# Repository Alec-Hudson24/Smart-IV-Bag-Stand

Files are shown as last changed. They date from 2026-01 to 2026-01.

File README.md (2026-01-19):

# Smart-IV-Bag-Stand
**Automated, height-adjustable IV pole with real-time fluid level monitoring and low-fluid alerts**  
*(Group project: Mechanical design, electronics integration, Arduino programming)*

## Goal/ Overview
- **Primary Features**:
  - Motorized height adjustment: Automatically or manually raise/lower the IV bag between 5 ft and 7 ft for ergonomic patient/nurse access.
  - Continuous fluid level tracking: Uses a load cell/weight sensor to monitor IV bag volume.
  - Low-fluid alert: Buzzer sounds and visual indicator activates when fluid drops below 20%.
- **Motivation**: Improve hospital efficiency and patient safety by reducing manual adjustments and preventing dry IV bags.
- **Outcome**: Fully functional prototype with joystick/rotary dial controls, LED feedback (green/yellow/red for full → low), calibration button, and hinged access panel for electronics.

## Programs and skills required
- **3D Modeling & Design**: SolidWorks (parametric modeling, assemblies, STEP export for prototyping/fabrication)
- **Electronics**: Soldering, PCB connections, integration of load cell, motors, joystick, rotary encoder, LEDs, buzzer
- **Programming**: Arduino IDE (sensor reading, motor control, state machine for modes/alerts, calibration logic)
- **Other**: Team collaboration, project planning, fabrication/assembly

## Key Takeaways and lessons
- Align tasks with team members' interests → higher quality work and motivation.
- Clear, ongoing communication (plans, roles, timelines) keeps everyone aligned and reduces rework.
- Build team rapport outside project work → improves collaboration and problem-solving.

 # Project Links  
-Video explanation and test: [IV Bag Stand Demo](https://www.youtube.com/watch?v=gjZ4MjLh-VY)  
-Code Powering This Project: [Code](https://github.com/Alec-Hudson24/Smart-IV-Bag-Stand/blob/main/Final_With_Automatic_Raise_Lower.ino)  
-Step File to Prototype: [Solidworks prototype](IV%20Project.STEP)  
-Final Design Report: [Report](https://github.com/Alec-Hudson24/Smart-IV-Bag-Stand/blob/main/Final%20Design%20Report%20IV%20Bag%2011_26_25.pdf)

## Future Improvements / Ideas
- Add wireless alerts (e.g., Bluetooth to nurse station app)
- Integrate battery monitoring
- Refine mechanical stability for taller extensions
- Design custom PCB to simplify the wiring

# Model Photo
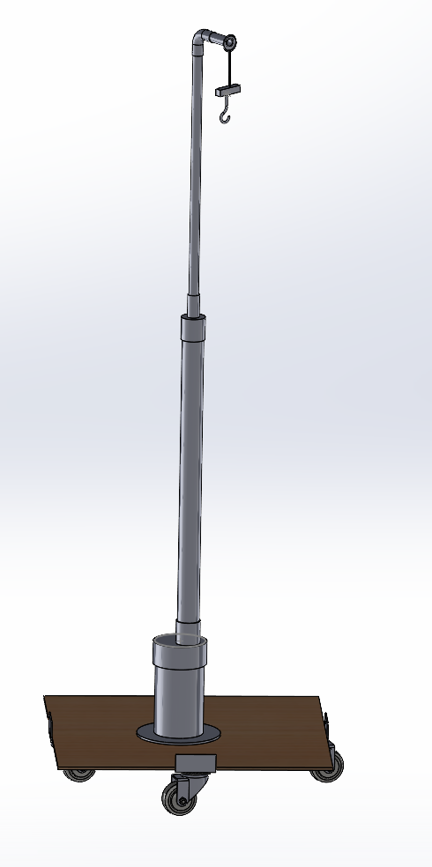
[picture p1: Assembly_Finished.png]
Finished IV Holder Assembly


*This was for a class called Concepts in Mechanical Design*

[Back](https://github.com/Alec-Hudson24)

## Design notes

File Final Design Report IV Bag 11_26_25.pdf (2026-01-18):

# Final Design Report Team 13

Alec Hudson, Jenna Sapong, Myles Knot, Caleb Crunk, Jackson Lynd

| Mech 3200 | assignment: Final Design Report IV Bag
Section 1 Team 13 | file: Final Design Report – Team 13 | 1 | Page

## Design Presentation

Executive Summary

This report details the IV bag height adjustment mechanism, an automated motorized IV pole with refill notification. It employs the following:
- Linear actuator for 5-7 ft height adjustment in <36 sec
- Load cell for fluid monitoring (alert at ~90 mL/0.09 kg)
- Arduino controls with joystick input
- Audible and Visual user feedback
- Stable and compact design
The design meets all DRS, costs $364.51, and outperforms manual poles in safety and efficiency. Trial readiness is proven through acceptance tests and performance metrics.
Machine Function
The device adjusts IV bag height (5-7 ft) via joystick and alerts via chime when fluid is low. It maximizes usability features across stakeholders of Users, Owners, Manufacturers and Support.

Design Requirement Specifications (DRS)
- Height: 5-7 ft in <36 sec.
- Load: 2.2-4.4 lbf (0.998 kg – 2kg).
- Alert at ~90 mL (0.09 kg).
- Budget: <$400.
- Alert Sound: >50 dB.
- Stability: No tipping/ease of transport.
Competitive Advantages
- Linear actuator chosen over rack/pinion or lever for off-the-shelf simplicity, constant velocity (1.34 in/s), and high load (89.9 lbf / 40.78 kg). Superior to manually lifting IV bags by reducing repetitive injuries, enabling single-user operation and auto-alert when bag is near empty.

Alec Hudson, Jenna Sapong, Myles Knot, Caleb Crunk, Jackson Lynd

| Mech 3200 | assignment: Final Design Report IV Bag
Section 1 Team 13 | file: Final Design Report – Team 13 | 2 | Page
- This design is optimized for stability and ease of transport as it retracts to the lowest compact size possible (under 5 feet) making moving through doorways and onto elevators is much simpler.
- Eliminates all manual efforts of lifting IV bags resulting in reduction of repetitive injury claims Proving Trial Readiness
Acceptance tests: Height adjustment 13.6 sec (pass); load to 4.4 lbf stable (pass); alert at 0.09 kg (pass); alert sound >50 dB (pass).
Performance Matrix
Requirement | Target | Performance | Status
Height | 5-7 ft | 5-7 ft (24” extension) | Pass
Time | <36 sec | 17.9 sec | Pass
Load | 2.2-4.4 lbf (0.998 kg – 2kg) | 89.9 lbf (40.78 kg) | Pass
Change in Mass Sensitivity | 0.005 kg | δ! = 0.005 kg (10 kg cell) | Pass
Budget | <$400 | $370.01 | Pass
Sound | >50 dB | ~90 dB | Pass

Cost Analysis
Bill of Materials
Component | OEM | Part Number | QTY | Cost/Unit | Total
Linear Actuator | JQDML | B0DH254XYJ | 1 | $104 | $104.00
MicroController | Arduino | Uno Rev3 | 1 | $27.60 | $27.60
LED Wheel | Adafruit | LED Ring Light | 1 | $16.95 | $16.95
Motor Shield | Arduino | Rev3 | 1 | $28.40 | $28.40
Thumb Joystick | Arduino | Grove | 1 | $6.00 | $6.00
Audio Buzzer | Passive Buzzer Naroote | | 1 | $0.50 | $0.50
Hanging Load Cell | DigiKey | 1568-21669-ND | 1 | $23.10 | $23.10
Plywood Base | Home Depot | 24”x24” | 1 | $12.87 | $12.87
PVC Tube Support | JM Eagle | 6”x10 ft D2729 | 1 | $26.31 | $26.31

Alec Hudson, Jenna Sapong, Myles Knot, Caleb Crunk, Jackson Lynd

| Mech 3200 | assignment: Final Design Report IV Bag
Section 1 Team 13 | file: Final Design Report – Team 13 | 3 | Page
PVC Flange Mount | Jones Stephens 7 in. O.D. | | 1 | $20.26 | $20.26
PVC Tube Extender | IPEX | 1/2 in. x10 ft SCH 40 | 2 | $4.96 | $9.92
PVC Connectors | Charlotte Pipe | 1/2 in. Coupling | 3 | $0.70 | $2.10
Caster Wheel Base | WEN | 24”x24” Dolly | 1 | $54.60 | $54.60
Handle | Manufactured | - | 1 | $20.00 | $20.00
Position Encoder | Arduino | KY-040 | 1 | $2.40 | $2.40
Misc. Hardware | Home Depot | Bolts/Nuts/Washers | 50 | $0.18 | $9.00
Total | | | | | $364.51
Final Design Overview
Key functionality for final IV Bag lift system that this design incorporates
- PVC/plywood base with casters for stability and low center of gravity
- Linear actuator for extension to required height, simple off-the-shelf components and compactness
- Load cell at top for weight/volume measurement providing required δ! mass sensitivity
- Arduino controller with joystick user input.
- LED visual level and calibration indicator and audible alert chime.
- Automates height and alerts low and empty fluid levels.

Alec Hudson, Jenna Sapong, Myles Knot, Caleb Crunk, Jackson Lynd

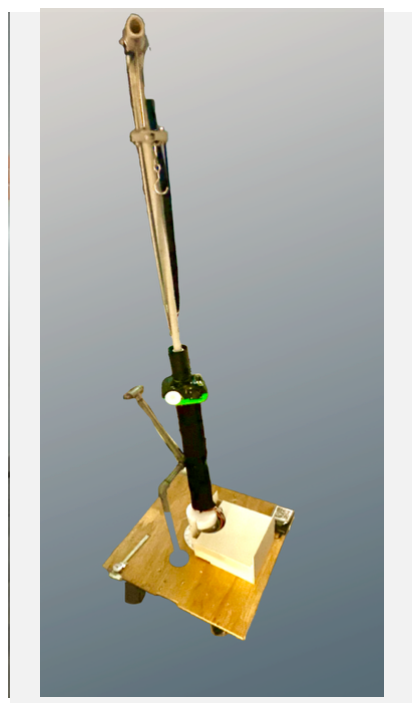
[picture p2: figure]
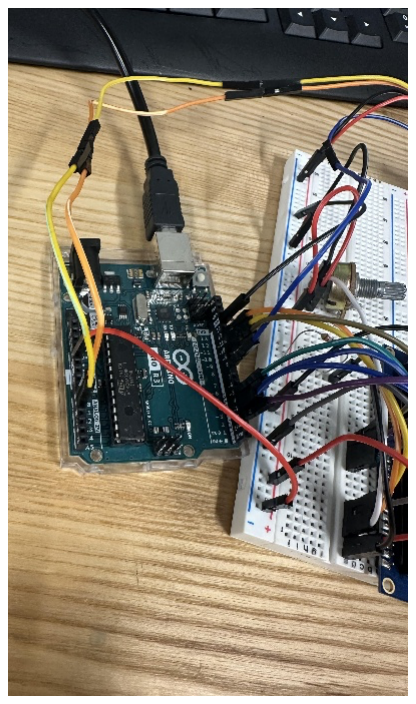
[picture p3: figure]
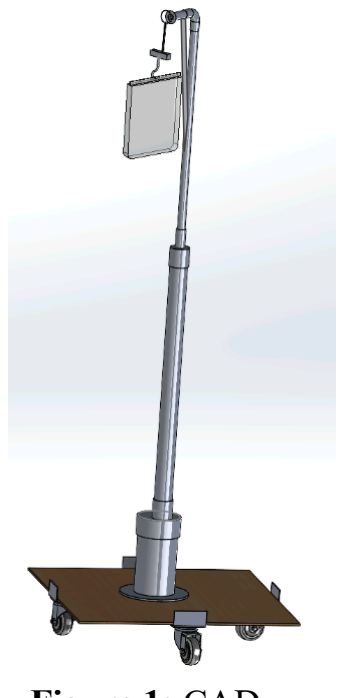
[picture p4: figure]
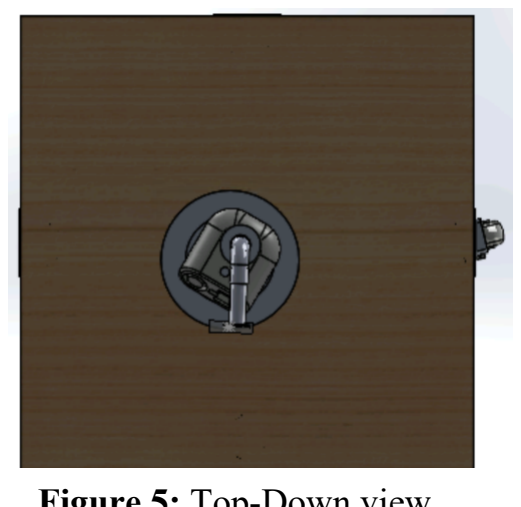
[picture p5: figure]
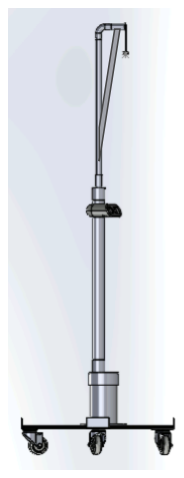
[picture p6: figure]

| Mech 3200 | assignment: Final Design Report IV Bag

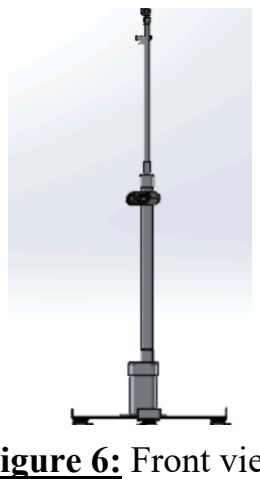
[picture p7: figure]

Section 1 Team 13 | file: Final Design Report – Team 13 | 4 | Page

CAD Model
SolidWorks model: Retracted (5 ft) and extended (7 ft) views, labeled base, actuator, load cell, joystick, LCD, chime.
- Figure 1: Depicts the CAD model that was used to build and wire the actual Device.
- Figure 2: Shows the wiring on the Arduino microcontroller that combines all the components into one device.
- Figure 3: Pictures the working IV stand prototype, completed, tested and operational. 3-View Line Drawings
Figure 1: CAD | Figure 2: Wiring | Figure 3: Machine as built
Figure 4: Side View | Figure 5: Top-Down view | Figure 6: Front view

Alec Hudson, Jenna Sapong, Myles Knot, Caleb Crunk, Jackson Lynd

| Mech 3200 | assignment: Final Design Report IV Bag
Section 1 Team 13 | file: Final Design Report – Team 13 | 5 | Page
- Figure 4: Depicts the side view providing a profile angle of the hook and loadcell showing 60-84” height range and caster mounting
- Figure 5: Shows the plan view which includes the profile of the IV stand and demonstrates the stable base with 24” square footprint
- Figure 6: shows the front view giving a good view of the user input control panel

Manufacturing Overview
Purchased Components | Fabricated Components
Arduino Controller/Wiring | 3D printed parts
Linear actuator | Assembly
Switches | Transportation Handle

Materials

Load Cell

Assembling components together and developing the code for this project was the main challenge, once the code was developed manufacturing was straight forward to meet DRS goals.

Key Manufacturing Process Steps
1. Bolt casters to 24” square base
2. Mount PVC Base in center of base
3. Install actuator and 3D printed cap
4. Install additional PVC assembly to house actuator
5. Install Load Cell and Lifting Arm
6. Wire Arduino per Figure 2 and upload operating software
7. Test Assembly for performance to design requirement specs Total assembly and test time ~2 hours

Alec Hudson, Jenna Sapong, Myles Knot, Caleb Crunk, Jackson Lynd

| Mech 3200 | assignment: Final Design Report IV Bag
Section 1 Team 13 | file: Final Design Report – Team 13 | 6 | Page

Conclusion

The IV bag design prioritizes accuracy and ease of assembly, aiding medical staff and manufacturers through intuitive user interfaces and precise load sensing. It meets all design requirements and delivers optimal performance for the environment it services. Ass seen in the Proving Trail Readiness section, this design meets or exceeds all design requirment specifications.

Design Methodology
Problem Statement and Customer Needs
Manual IV pole adjustments cause repetitive stress injuries, inefficiency, and lost revenue due to unchecked fluid levels.
The customer needs are as follows:
- Automated IV Bag elevation that is easily adjustable and single-user capable (End-User)
- Efficient that requires no manual labor (reduced claims) and alerts for IV bags nearing/reaching empty (Owners)
- Easy to assemble and low cost (Manufacturers)
- Modular design and stability allows for easy transportation, maintenance and troubleshooting (Support)

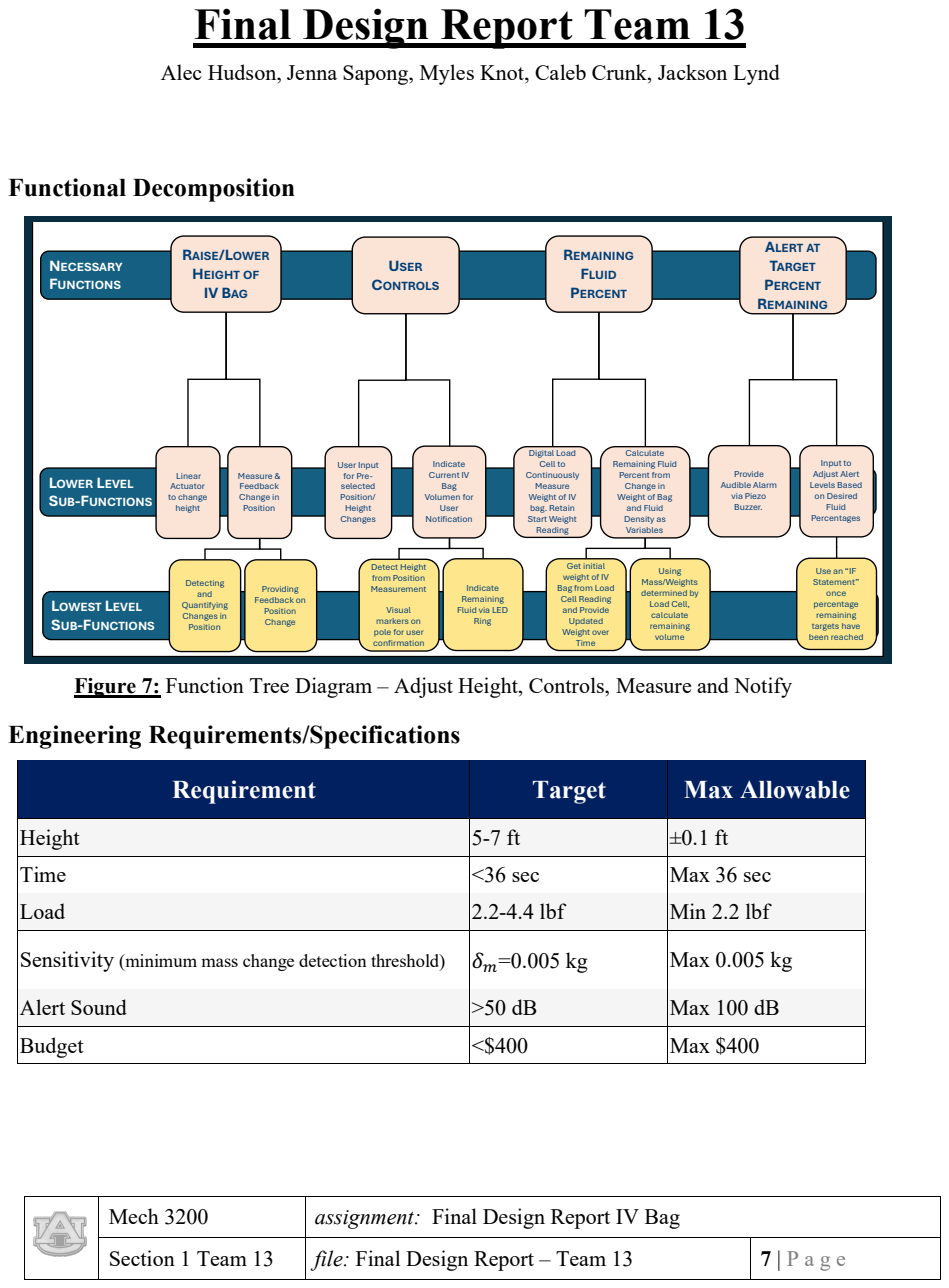
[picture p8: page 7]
Functional Decomposition; NECESSARY FUNCTIONS; LOWER LEVEL SUB-FUNCTIONS; USER CONTROLS; User Input for Pre- selected Position/ Height Changes; Indicate Current IV Bag Volumen for User Notification; REMAINING FLUID PERCENT; RAISE/LOWER HEIGHT OF IV BAG; Linear Actuator to change height; Measure & Feedback Change in Position; ALERT AT TARGET PERCENT REMAINING; Provide Audible Alarm via Piezo Buzzer.; Input to Adjust Alert Levels Based on Desired Fluid Percentages; LOWEST LEVEL SUB-FUNCTIONS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

Alec Hudson, Jenna Sapong, Myles Knot, Caleb Crunk, Jackson Lynd

Digital Load
Cell to
Continuously
Measure
Weight of IV
bag. Retain
Start Weight
Reading

Calculate
Remaining Fluid
Percent from
Change in
Weight of Bag
and Fluid
Density as
Variables

Get initial
weight of IV
Bag from Load
Cell Reading
and Provide
Updated
Weight over
Time

Use an “IF
Statement”
once
percentage
remaining
targets have
been reached

Indicate
Remaining
Fluid via LED
Ring

Visual
markers on
pole for user
confirmation

Figure 7: Function Tree Diagram – Adjust Height, Controls, Measure and Notify
Engineering Requirements/Specifications

Requirement | Target | Max Allowable

Height | 5-7 ft | ±0.1 ft
Time | <36 sec | Max 36 sec
Load | 2.2-4.4 lbf | Min 2.2 lbf

Sensitivity (minimum mass change detection threshold) | δ!=0.005 kg | Max 0.005 kg

Alert Sound | >50 dB | Max 100 dB
Budget | <$400 | Max $400

Mech 3200 | assignment: Final Design Report IV Bag
Section 1 Team 13 | file: Final Design Report – Team 13 | 7 | Page

Alec Hudson, Jenna Sapong, Myles Knot, Caleb Crunk, Jackson Lynd

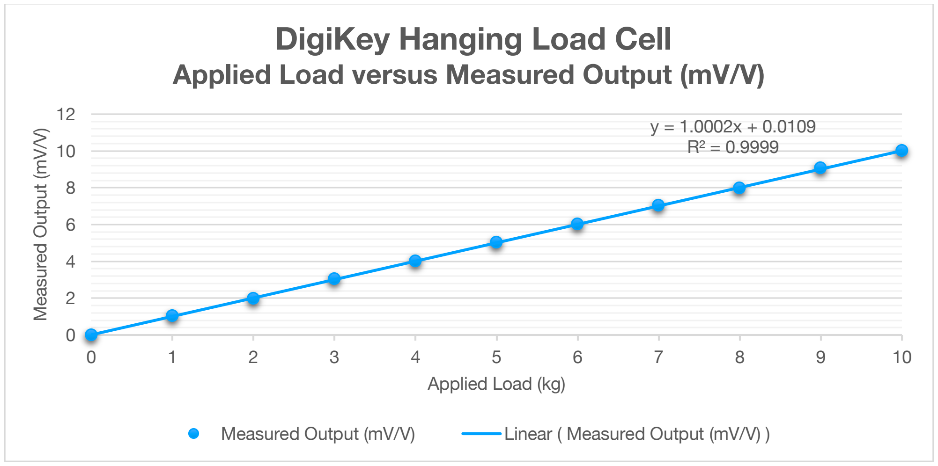
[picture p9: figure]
Measured Output (mV/V); Applied Load (kg); DigiKey Hanging Load Cell

| Mech 3200 | assignment: Final Design Report IV Bag
Section 1 Team 13 | file: Final Design Report – Team 13 | 8 | Page

Chart1: Applied load versus voltage output for the DigiKey hanging load cell.

The load cell provides very predictable and stable voltage output across measured loads. This ensures reliability for calculating remaining fluid measured in the IV bag.

Based on the OEM specs of the load cell and expected loading use-cases, the hanging load cell will provide excellent resolution.
- 1 mL detectability on a 1L bag
- Provides the 0.05% mass change sensitivity accuracy and delivers required design precision up to 4,400mL (4.4 kg) load
- This system works for all common sizes of IV bags (50mL to 1,000mL) and can accommodate larger 3,000mL IV bags sometimes used in specialized trauma centers

### Applied Load versus Measured Output (mV/V)

Measured Output (mV/V) | Linear ( Measured Output (mV/V) )

Alec Hudson, Jenna Sapong, Myles Knot, Caleb Crunk, Jackson Lynd

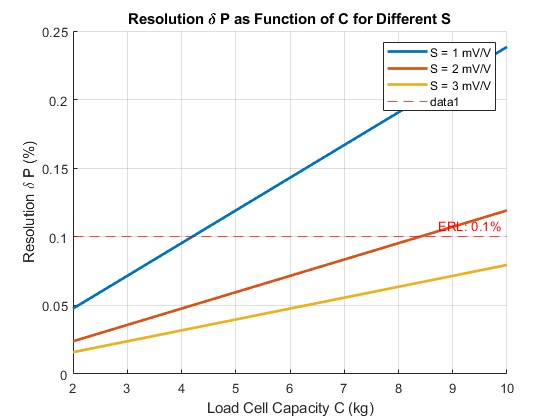
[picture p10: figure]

| Mech 3200 | assignment: Final Design Report IV Bag
Section 1 Team 13 | file: Final Design Report – Team 13 | 9 | Page

A parametric contour plot was generated using MATLAB and the OEM performance sheet data to visualize ERM uncertainty across the design space.

Line Color | Sensitivity S (mV/V) | Slope Behavior | Resolution at 10 kg
Blue | 1 mV/V | Steepest | ~0.10% (1 g)
Orange | 2 mV/V | Medium | ~0.05% (0.5 g)
Yellow | 3 mV/V | Flattest | ~0.033% (0.33 g)
- All lines are straight and rising → δP increases linearly with C
- Higher S = lower δP → better ability to detect small weight changes

Alec Hudson, Jenna Sapong, Myles Knot, Caleb Crunk, Jackson Lynd

| Mech 3200 | assignment: Final Design Report IV Bag
Section 1 Team 13 | file: Final Design Report – Team 13 | 10 | Page

Concept Generation
The morphological matrix provides an overview of initial design concepts that were used to identify a preliminary solution.
LLSF | WP1 | WP2 | WP3
Raising and lowering | Screw Driven Motor | Linear Actuator | Lever to Move IV Pole Height
Measuring Height | Potentiometer Sensor | Optical Sensor | Ultrasonic Rangefinder
User Input and Feedback | Button | Joystick | LCD Light Ring
Calculating Fluid Remaining | Load Cell | Optical Sensor | Timer

From these, a weighted decision matrix was created to select the design to be manufactured.

Need | Weight | Concept Variation 1 | Concept Variation 2 | Concept Variation 3
Raising & Lowering | 1.0 | Linear Actuator S=1 | Rack & Pinion S=0.8 | Lever Arm S=0.25
Measuring height | 0.5 | JQDML Acutator Internal Potentiometer S=1 | Constant Velocity Extention shaft S=.7 | Optical Sensor S=0.25
Remaining IV Fluid Measurement | 0.9 | Load Cell S=1 | Digital Scale S=0.6 | Timer S=0.25

Alec Hudson, Jenna Sapong, Myles Knot, Caleb Crunk, Jackson Lynd

| Mech 3200 | assignment: Final Design Report IV Bag
Section 1 Team 13 | file: Final Design Report – Team 13 | 11 | Page

Final Design Solution and Single Alternative

Design Manufactured | Alternative
Linear Actuator Purchased | Lead screw to push up PVC- a lead screw would be rotated with a motor to push up the pvc pipe
Load Cell Purchased | Optical Sensor to measure fluid level- would see the level of fluid go down visually
Joystick & Position Encoder | Touch screen- to control machine and control function
LED ring light | LCD screen- would be used to display fluid level and linear actuator position
Passive Alarm | Active alarm- is one frequency, so pitch can’t be changed
User Feedback/Alarm System | 0.7 | Chime S=1 | Piezo Buzzer S=0.9 | Speaker S=0.95
Ease of Transport, Stability | 0.9 | Ballast to the bottom S=1 | Wide Base S=0.9 | Bolt down /Locking S=0.7
Satisfaction Score | | 4.0 | 3.13 | 1.9

Alec Hudson, Jenna Sapong, Myles Knot, Caleb Crunk, Jackson Lynd

| Mech 3200 | assignment: Final Design Report IV Bag
Section 1 Team 13 | file: Final Design Report – Team 13 | 12 | Page

Targeted design

Design Targets: | Status
IV stand moves up and down between 5ft and 7ft | MET
Loadcell tracks weight | MET
Buzzer goes off when loadcell reads lower than 20% weight | MET
Stability | MET

## Design Development

Engineering Requirements Level Assurance

Requirement | Assurance
Height | • Height was measured from lowest point was equal to 5ft • Height was measured from highest point was equal to 7ft
Time | • Speed of linear actuator measured 1.34 in/s and extends the required 2 ft in 17.9 seconds
Load | • Supports the weight of a 1,000 mL IV bag (1 kg) and more. This was tested and verified with different weighted objects
Sensitivity | • Load cell was tested with two objects of slightly differing weight and was accurate within 1%
Sound Buzzer | • ~90 dB which was tested with an iPhone decibel reader
Budget | • Project stayed within the constraints of the budget and, is able to fulfil every engineering requirement

Design For Considerations (DFX)

DFX | Consideration or Goal
DFV: Designed for velocity | The linear actuator was selected to have the functionality of speed so it could complete position movements in less than 35 seconds. It’s

Alec Hudson, Jenna Sapong, Myles Knot, Caleb Crunk, Jackson Lynd

| Mech 3200 | assignment: Final Design Report IV Bag
Section 1 Team 13 | file: Final Design Report – Team 13 | 13 | Page
| load capacity has a sufficiently high safety margin that speed is not affected under all expected loading use cases
DFS: Designed for Stability | The base was made with extremely low center of gravity, heavy and wide, to prevent any tipping. Additionally, design was optimized to allow for retraction to lowest height possible for transport and movement. These two design factors ensure the IV stand will not tip and cause damage or lost productivity. Passing through doorways and elevators was a major consideration for compactness.
DFM: Designed for Manufacturing | This was designed to use off the shelf components making manufacturing easy and reliable. Additionally, 3D printed components keep customized part cost extremely low and can be used to make molds for low-cost mass production.
DFS: Designed for Serviceability | All the wires and mechanical components are easy to troubleshoot, disassemble and replace making repairs simple and fast.

FMEA with Design Correction

Failure Mode | Severity | Occurrence | Detection | RPN | Action | Correction RPN
Actuator runs past 7ft | 3 | 5 | 1 | 15 | No action necessary, position reader added to code | 15
Load cell stops reading fluid level | 10 | 4 | 10 | 400 | Add in alarm start if Load cell is not detected | 40
Battery dies | 10 | 3 | 5 | 150 | Low power mode added for detection | 30

Alec Hudson, Jenna Sapong, Myles Knot, Caleb Crunk, Jackson Lynd

| Mech 3200 | assignment: Final Design Report IV Bag
Section 1 Team 13 | file: Final Design Report – Team 13 | 14 | Page
Joystick Failure | 9 | 2 | 10 | 180 | Add secondary input selector button | 20
Audible Feedback Failure | 3 | 1 | 10 | 30 | No Action Necessary, rely on LED Ring for feedback | 30

Closes Loop Between Measured Performance and Engineering Specifications
- All Engineering Requirements are met and accounted for and are demonstrable via the first article assembly that was manufactured and presented.
- Measured Performance is as follows:
- Extension time between 5 feet and 7 feet is 17.9 seconds (<36 required)
- Change in mass sensitivity is 1 g (5g is requirement)
- Visual feedback for changes in weight/volume remaining including 10% remaining fluid and when empty
- Audible feedback at 10% remaining fluid and when empty
AT-A-GLANCE

Meets all Design Requirement Specifications

PERFORMANCE | BENEFIT
50% Faster Deployment | Efficiency Gains
9% Cheaper than budget | Cost Effective/More Profit
5 times more sensitive to changes in mass of IV Bag | Finer Fluid Level Monitoring
20x greater load capacity | Ensures robustness and can support multiple IV bags within same unit
Full IV Bag compatibility 50mL to 3,000 mL sizes | Covers 100% of standard and trauma-center applications; validated via load cell resolution
Compact and Stable Portabilty | 98% of mass is within six inches to the ground, 24” square footprint with multi-surface capable casters
100% Functional Compliance | Passes all acceptance criteria for autonomous operation, height range 4-7 ft, and fluid monitoring and audible/visual alerts with easy-to-use UI/UX

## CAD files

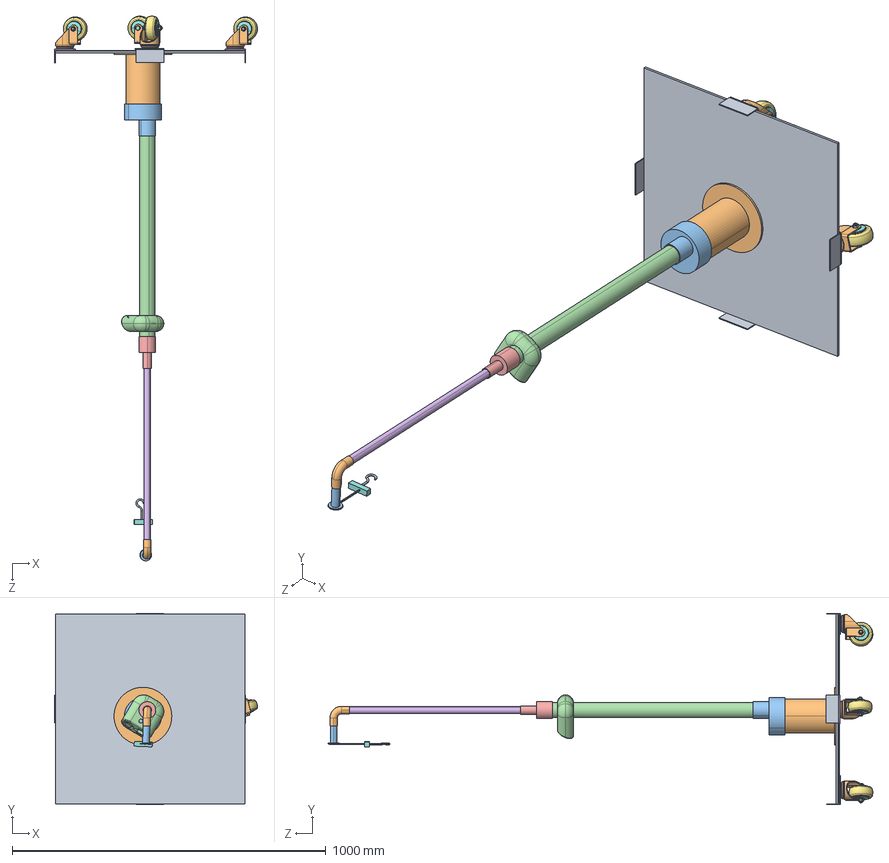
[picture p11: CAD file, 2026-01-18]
IV Project.STEP
647.2 x 609.6 x 1736.7 mm
drum dolly
A-PIN-S x 4
A-AX46 x 4
A-R x 4
TPP1 x 4
TPR-3-T x 4
TPR-3-TG x 8
Part11_Wood_Base
Part12_PVCBase
CapV2
Part13_MediumPVC
Small Cap V2
Part14_SmallPVC
Part 5_ Load Cell NEWNEW
Part 6_ Hook (1) NEWNEW
Part15_PVCElbow
Part16_SmallPVC_HangOver
JoystickAndLEDHolder

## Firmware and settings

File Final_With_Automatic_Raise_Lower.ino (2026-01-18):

#include "HX711.h"
#include <Adafruit_NeoPixel.h>

#define NEO_PIN            6
#define NUM_LEDS          12
Adafruit_NeoPixel ring(NUM_LEDS, NEO_PIN, NEO_GRB + NEO_KHZ800);
const uint8_t ledOrder[12] = {1,2,3,4,5,6,7,8,9,10,11,0};

const int dirA             = 12;
const int pwmA             = 3;
const int brakeA           = 9;
const int vryPin           = A3;
const int BUTTON_PIN       = 4;
const int BUZZER_PIN       = 8;
const int LOADCELL_DT_PIN  = 5;
const int LOADCELL_SCK_PIN = 2;

#define ENCODER_CLK   10
#define ENCODER_DT    11
#define ENCODER_SW     7

const float ACTUATOR_SPEED_INCHES_PER_SEC = 1.33858;
const int ACTUATOR_PWM = 250;
float actuatorPositionInches = 0.0;

HX711 scale;
float calibration_factor = -7050.0;
float empty_weight = 0.0, full_weight = 0.0;
const unsigned long HOLD_TIME = 500;

int neutralY = 512;
const int upThreshold   = neutralY + 150;
const int downThreshold = neutralY - 150;

bool button_held = false, action_triggered = false, weight_set = false;
unsigned long button_press_time = 0;

float cached_percent = 100.0;
unsigned long last_scale_read = 0;
bool actuator_moving = false;

int currentLedCount = 0;           // positive = green/up, negative = red/down
int committedLedCount = 0;
bool encoderModeActive = false;
unsigned long lastRotationTime = 0;
const unsigned long REVERT_TIMEOUT = 3000;

int8_t lastA = -1, lastB = -1;

// Your original alarm tune
const int alarm_melody[] = {
  523,659,784,1047,784,659,523,440,880,1047,1319,1760,1319,1047,880,784,
  587,698,880,1175,880,698,587,523,1047,1319,1568,2093,1568,1319,1047,784
};
const int alarm_durations[] = {
  120,120,120,240,120,120,120,240,120,120,120,240,120,120,120,240,
  120,120,120,240,120,120,120,240,120,120,120,240,120,120,120,120
};
const int TUNE_LEN = 32;

bool alarm_active = false;
int note_index = 0;
unsigned long last_note_time = 0;

void ledsOff() { ring.clear(); ring.show(); }

void setRingPreview(int count) {
  ring.clear();
  int a = abs(count);
  uint32_t col = (count > 0) ? ring.Color(255,0,0) : ring.Color(0,255,0);  // Green = up, Red = down
  for (int i = 0; i < a; i++) ring.setPixelColor(ledOrder[i], col);
  ring.show();
}

// PERFECT 38.64 SECOND FULL STROKE – SCALES LINEARLY
void moveActuatorInches(float inches) {
  if (abs(inches) < 0.01) return;

  bool extend = (inches > 0);
  int absLedCount = abs(currentLedCount);
  if (absLedCount == 0) return;

  const unsigned long FULL_STROKE_MS = 38640UL;           // 38.64 seconds
  unsigned long duration = (FULL_STROKE_MS * absLedCount) / 12;  // perfect scaling

  digitalWrite(brakeA, LOW);
  digitalWrite(dirA, extend ? HIGH : LOW);
  analogWrite(pwmA, ACTUATOR_PWM);
  ledsOff();
  actuator_moving = true;

  unsigned long start = millis();
  while (millis() - start < duration) {
    int y = analogRead(vryPin);
    if (y > upThreshold || y < downThreshold) {
      analogWrite(pwmA, 0);
      digitalWrite(brakeA, HIGH);
      actuator_moving = false;
      return;
    }
    delay(1);
  }

  analogWrite(pwmA, 0);
  digitalWrite(brakeA, HIGH);
  actuator_moving = false;

  actuatorPositionInches += inches;
  committedLedCount = currentLedCount;
  currentLedCount = 0;
  setRingPreview(0);
  encoderModeActive = false;
}

void startupWithBeeps() {
  ring.clear();
  for (int i = 0; i < 12; i++) {
    ring.setPixelColor(ledOrder[i], ring.Color(0, 0, 150));
    ring.show();
    tone(BUZZER_PIN, 900 + i*100, 40);
    delay(70);
  }
  noTone(BUZZER_PIN);
  ledsOff();
}

void smoothGreenFillWithBeeps() {
  ring.clear(); ring.show();
  tone(BUZZER_PIN, 1500, 100); delay(120);
  tone(BUZZER_PIN, 2000, 150); delay(180);
  for (int i = 0; i < 12; i++) {
    ring.setPixelColor(ledOrder[i], ring.Color(0, 255, 0));
    ring.show();
    delay(50);
  }
  noTone(BUZZER_PIN);
  delay(150);
}

void updateWeightDisplay() {
  if (millis() - last_scale_read >= 300) {
    float current = scale.get_units(5);
    if (current < empty_weight) current = empty_weight;
    cached_percent = ((current - empty_weight) / (full_weight - empty_weight)) * 100.0;
    cached_percent = constrain(cached_percent, 0, 100);
    last_scale_read = millis();
  }
  int ledsOn = (int)(cached_percent * 12 / 100.0 + 0.5);
  ring.clear();
  uint32_t color = (cached_percent > 66.6) ? ring.Color(0,255,0) :
                   (cached_percent > 33.3) ? ring.Color(255,150,0) : ring.Color(255,0,0);
  for (int i = 0; i < ledsOn; i++) ring.setPixelColor(ledOrder[i], color);
  ring.show();
}

void setup() {
  Serial.begin(9600);
  ring.begin();
  ring.setBrightness(80);
  ring.show();

  scale.begin(LOADCELL_DT_PIN, LOADCELL_SCK_PIN);
  scale.set_scale(calibration_factor);
  scale.tare(15);

  pinMode(BUTTON_PIN, INPUT_PULLUP);
  pinMode(BUZZER_PIN, OUTPUT);
  pinMode(dirA, OUTPUT);
  pinMode(pwmA, OUTPUT);
  pinMode(brakeA, OUTPUT);
  pinMode(ENCODER_SW, INPUT_PULLUP);
  pinMode(ENCODER_CLK, INPUT_PULLUP);
  pinMode(ENCODER_DT,  INPUT_PULLUP);
  digitalWrite(brakeA, HIGH);

  empty_weight = scale.get_units(3);
  if (empty_weight < 0) empty_weight = 0;

  startupWithBeeps();
}

void loop() {
  int y = analogRead(vryPin);

  // Joystick control
  if (y > upThreshold || y < downThreshold) {
    digitalWrite(brakeA, LOW);
    digitalWrite(dirA, (y > upThreshold) ? HIGH : LOW);
    analogWrite(pwmA, ACTUATOR_PWM);
    actuator_moving = true;
    ledsOff();
    noTone(BUZZER_PIN);
    alarm_active = false;
    encoderModeActive = false;
    currentLedCount = 0;
    committedLedCount = 0;
  } else {
    analogWrite(pwmA, 0);
    digitalWrite(brakeA, HIGH);
    if (actuator_moving) actuator_moving = false;
  }

  // Rotary encoder – RIGHT = UP (GREEN), LEFT = DOWN (RED)
  if (!actuator_moving) {
    int8_t a = digitalRead(ENCODER_CLK);
    int8_t b = digitalRead(ENCODER_DT);

    if (a != lastA || b != lastB) {
      if (lastA == HIGH && a == LOW) {
        if (b == LOW)  currentLedCount++;      // RIGHT → GREEN → UP
        else           currentLedCount--;      // LEFT → RED → DOWN
      }
      currentLedCount = constrain(currentLedCount, -12, 12);

      encoderModeActive = true;
      lastRotationTime = millis();
      setRingPreview(currentLedCount);
    }
    lastA = a;
    lastB = b;
  }

  // 3-second timeout → revert
  if (encoderModeActive && millis() - lastRotationTime > REVERT_TIMEOUT) {
    currentLedCount = committedLedCount;
    setRingPreview(currentLedCount);
    encoderModeActive = false;
  }

  // Encoder button press → move actuator
  static bool lastSwState = HIGH;
  bool swState = digitalRead(ENCODER_SW);
  if (lastSwState == HIGH && swState == LOW) {
    if (currentLedCount != 0) {
      float inches = currentLedCount * 2.0;
      moveActuatorInches(inches);
    }
  }
  lastSwState = swState;

  // Set 100% button
  if (digitalRead(BUTTON_PIN) == LOW) {
    if (!button_held) {
      button_press_time = millis();
      button_held = true;
      action_triggered = false;
    } else if (!action_triggered && millis() - button_press_time >= HOLD_TIME) {
      float current = scale.get_units(10);
      if (current < empty_weight + 5.0) {
        Serial.println("Too light!");
        tone(BUZZER_PIN, 300, 400);
      } else {
        full_weight = current;
        weight_set = true;
        Serial.print("100% SET = "); Serial.println(full_weight, 2);
        smoothGreenFillWithBeeps();
      }
      action_triggered = true;
    }
  } else {
    button_held = false;
    action_triggered = false;
  }

  // Weight display & low-weight alarm
  if (!actuator_moving && weight_set && !encoderModeActive) {
    updateWeightDisplay();

    if (cached_percent <= 20.0) {
      if (!alarm_active) {
        alarm_active = true;
        note_index = 0;
        last_note_time = millis();
      }
      if (millis() - last_note_time >= alarm_durations[note_index]) {
        tone(BUZZER_PIN, alarm_melody[note_index]);
        note_index = (note_index + 1) % TUNE_LEN;
        last_note_time = millis();
      }
      if ((millis() / 125) % 2 == 0) {
        for(int i=0; i<12; i++) ring.setPixelColor(ledOrder[i], ring.Color(255,0,0));
      } else {
        ring.clear();
      }
      ring.show();
    } else if (alarm_active) {
      noTone(BUZZER_PIN);
      alarm_active = false;
      note_index = 0;
    }
  }

  // Serial monitor
  static unsigned long lastPrint = 0;
  if (millis() - lastPrint > 500) {
    Serial.print("Weight: "); Serial.print(scale.get_units(5),1);
    Serial.print("g → "); Serial.print(cached_percent,1); Serial.print("%");
    Serial.print(" | Pos: "); Serial.print(actuatorPositionInches, 2); Serial.println("\"");
    lastPrint = millis();
  }
}
